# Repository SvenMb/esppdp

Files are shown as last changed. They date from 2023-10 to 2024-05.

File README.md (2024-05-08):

#What is this?

This is the source repository for esppdp, which is a tiny VT-102 scale model housing an
ESP32 emulating a PDP11. You can connect a BlueTooth keyboard to it and play the
original Tetris, or do some die-hard computing on 2.11BSD.

#Why?

Well, someone had to put back the 'mini' in 'minicomputer', right?

---

This fork contains a set of patches to correct build errors in IDF 5.0
Ian Schofield (Isysxp)
October 2023

---

This fork integrates the sunton ESP32 2832S028 board. I try to do this in a way it simplifys the integration of other boards.
Patched for IDF 5.2.1

SvenMb
April 2024

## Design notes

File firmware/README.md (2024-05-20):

This is the code for a PDP11 simulation on an ESP32. It also contains some code for turning
an attached LCD into a VT52/IE15 terminal as well as using a BlueTooth keyboard as an input device.

Flash it onto a board, turn it on. If you want to use a keyboard, make sure it's discoverable
over BlueTooth within the first few seconds of the ESP32 turning on. Note that the paired
BT device afterwards will be detected automatically. Unfortunately there's no easy way to clear
the pairing to use a different keyboard without erasing the flash of the ESP32 (idf.py erase-flash).

This firmware works on either the final hardware (as detailed in the ../pcb directory) as well
as a standard ESP32-Wrover-Kit development board + LCD and a modified Sunton 2432S028 board. You can configure which board to run on
in menuconfig. (If your LCDs backlight doesn't turn on, you selected the wrong one.)

The firmware embeds a floppy disk containing RTX-11 as well as Tetris, and will start this up
automatically unless a FAT-formatted micro-SD-card with a file called 'rq.dsk' is detected. If
this file is detected, the firmware will configure a larger PDP11 and will start from the disk.
A pre-configured 2.11BSD disk has been provided in ../hard-disk-image.

To quicken uploads (if you're developing the code), you can comment out the
spiffs_create_partition_image line in CMakeLists.txt. This'll stop 'idf.py flash'
from uploading the Tetris floppy every time.

This firmware is developed on the current (11 jan 2021) master branch of ESP-IDF, but will likely
compile on ESP-IDF 4.2 and possibly other versions.

As of April 2024 it is patched for latest ESP-IDF 5.2.1 and compiles with that.

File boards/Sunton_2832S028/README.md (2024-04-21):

# Sunton ESP32 2832S028

The Sunton ESP32 2832S028 is avaiable for very cheap and integrates most of the needed hardware to run this PDP11 emulator.
Unfortunately they decided not to include PSRAM, so we have to add it to the board. But it is not that complicated.

I only have the newer version of this board with a ST7789 display, so you are are bit on yourself if you want to use the
older version with ILI9341, since the board layout changed.

## Modifications

Board before modification:
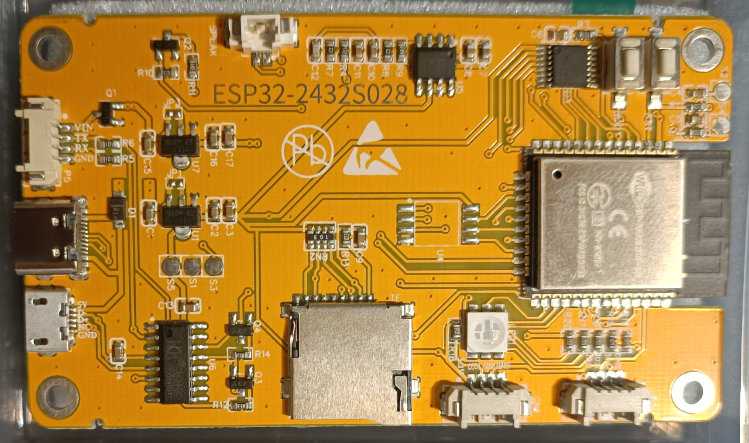
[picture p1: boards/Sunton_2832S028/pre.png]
pre modification


You have to remove the RGB-led and cut two lines:
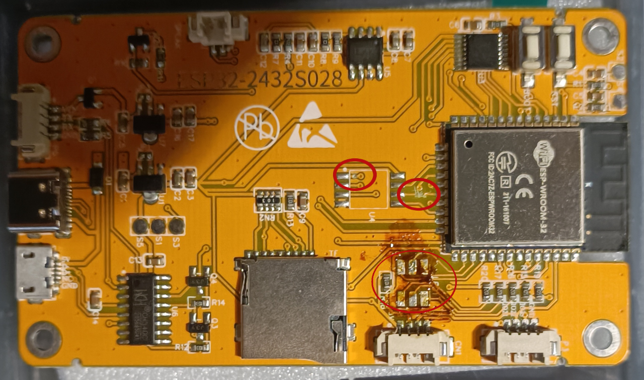
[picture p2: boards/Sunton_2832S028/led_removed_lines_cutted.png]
LED removal and lines cut


Now you can solder the PSRAM chip and add lines to the IO16, IO17 exposed on the former led place. Also add 10k pull-up as you can see here:
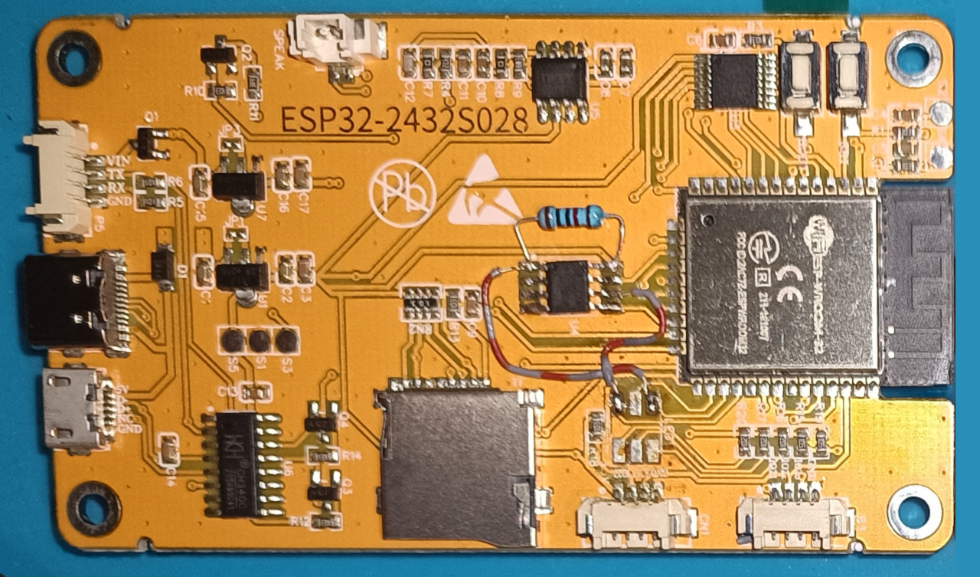
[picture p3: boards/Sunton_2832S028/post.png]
post modification


## flash firmware

after flashing the firmware and inserting the sdcard with the harddrive image, BSD 2.11 will boot:
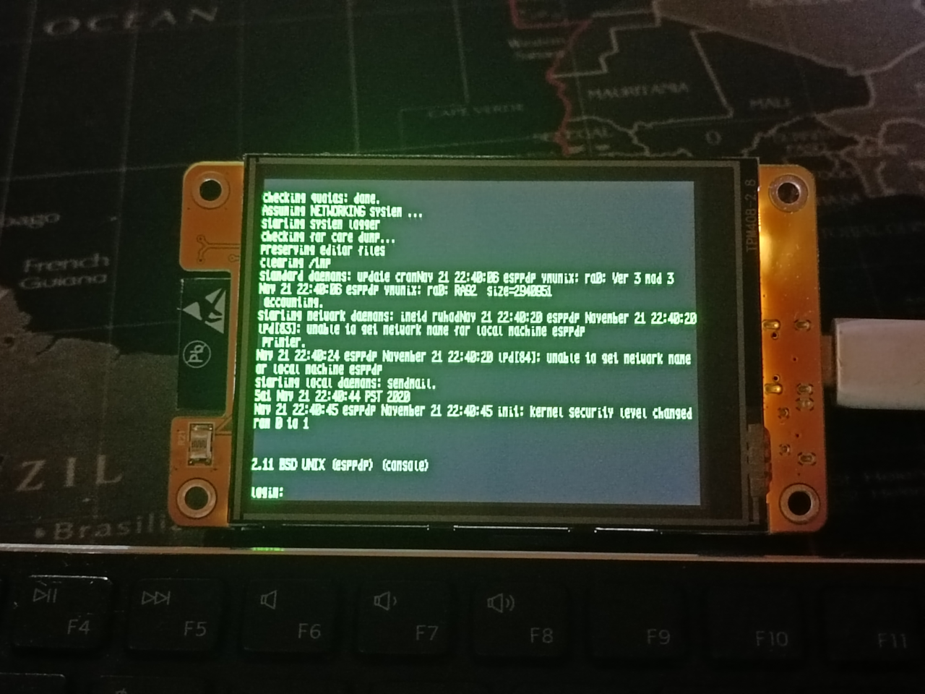
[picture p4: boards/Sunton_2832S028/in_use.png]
in use


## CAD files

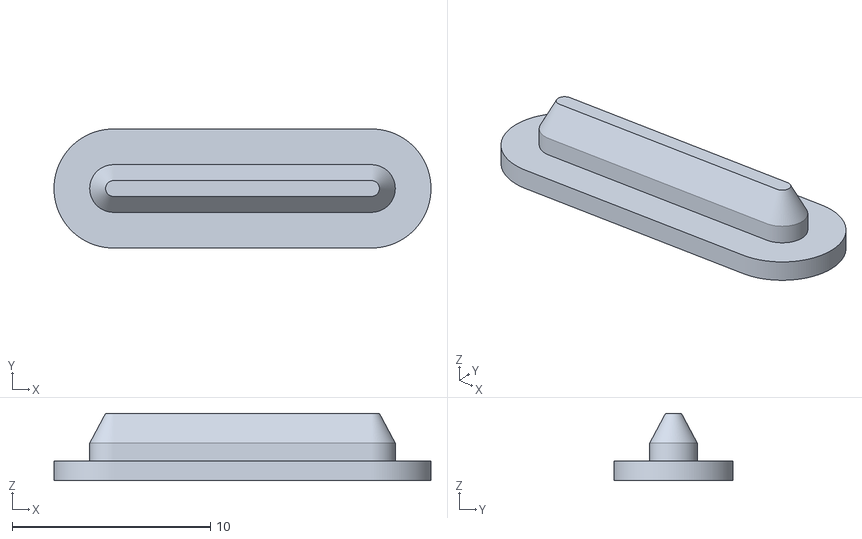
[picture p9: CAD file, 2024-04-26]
boards/Sunton_2832S028/case/MicroSD_2432S028.stl
19.0 x 6.00 x 3.40

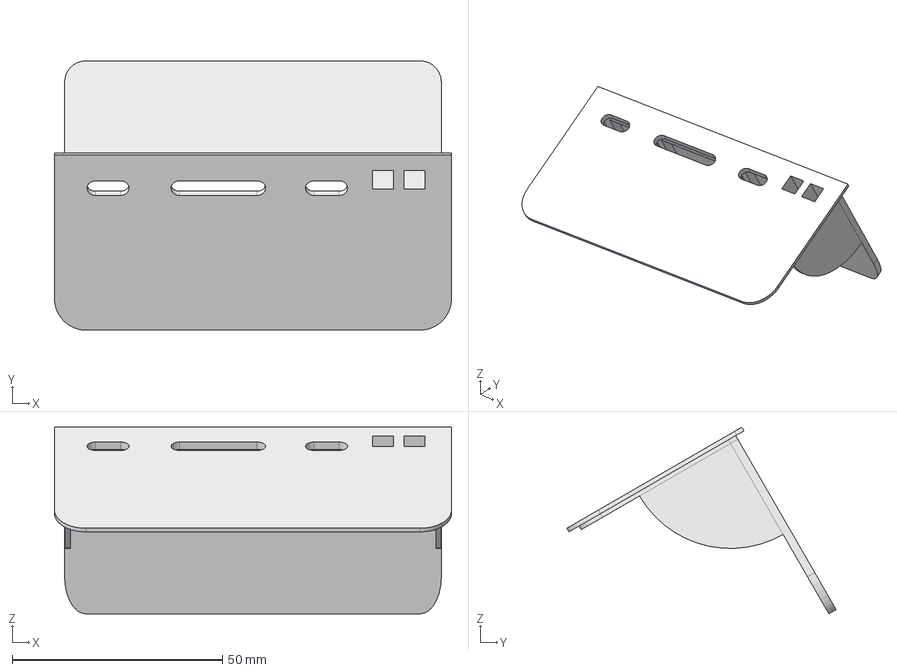
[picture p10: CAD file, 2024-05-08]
boards/Sunton_2832S028/case/2432S028_inner_03.FCStd
94.5 x 64.1 x 44.4 mm

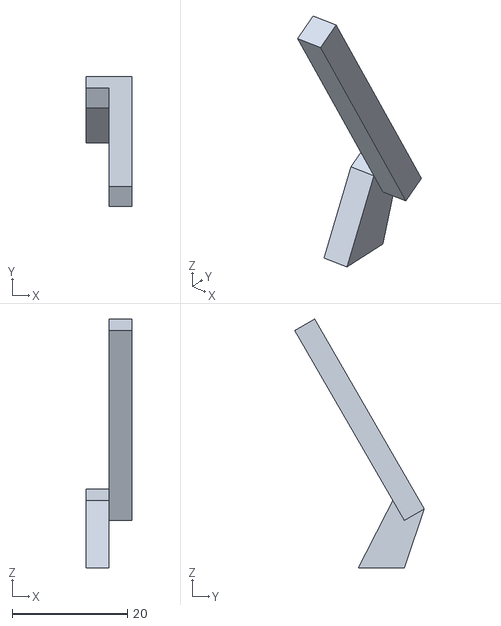
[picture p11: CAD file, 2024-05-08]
boards/Sunton_2832S028/case/2432S028_Pin_Reset.stl
8.00 x 22.5 x 43.1

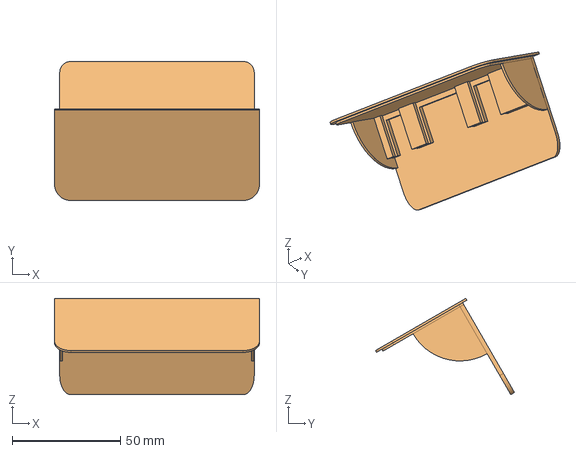
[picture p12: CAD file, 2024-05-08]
boards/Sunton_2832S028/case/2432S028_pins.FCStd
94.5 x 64.1 x 44.4 mm
Connect004

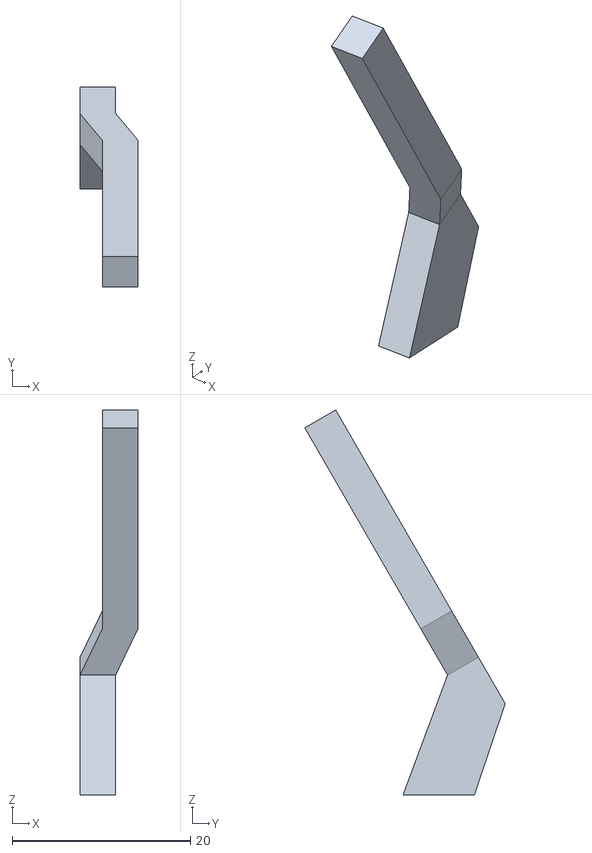
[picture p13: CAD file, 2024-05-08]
boards/Sunton_2832S028/case/2432S028_Pin_Boot.stl
6.50 x 22.5 x 43.1

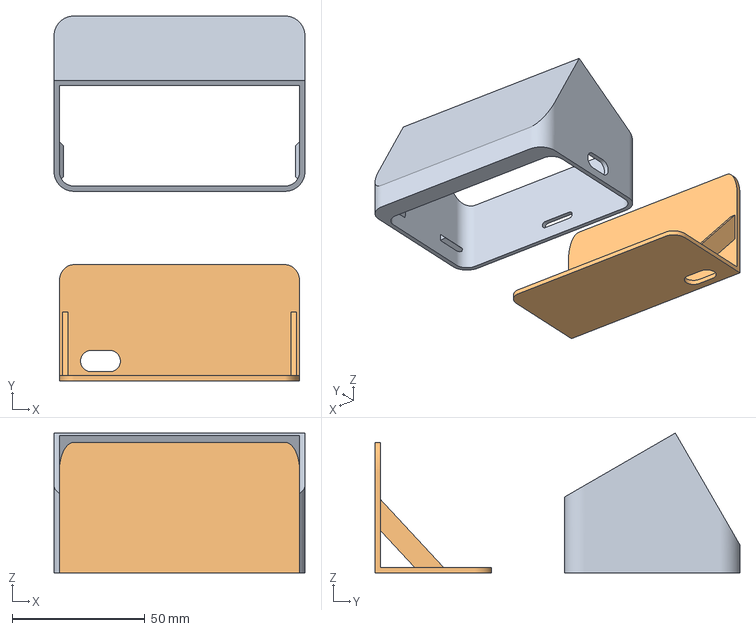
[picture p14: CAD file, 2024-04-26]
boards/Sunton_2832S028/case/2432S028_inner.FCStd
94.5 x 137.4 x 52.7 mm
Main (Meshed)
inner

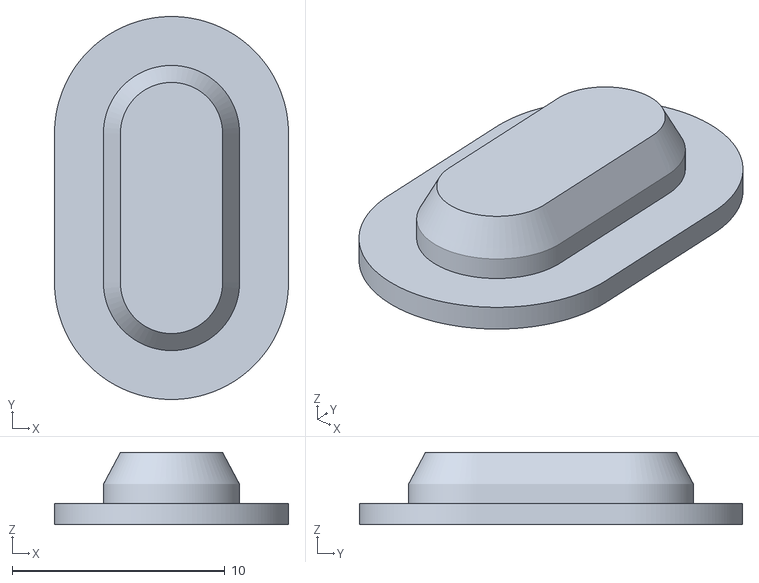
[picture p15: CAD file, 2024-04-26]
boards/Sunton_2832S028/case/2432S028_USB.stl
11.0 x 18.0 x 3.40

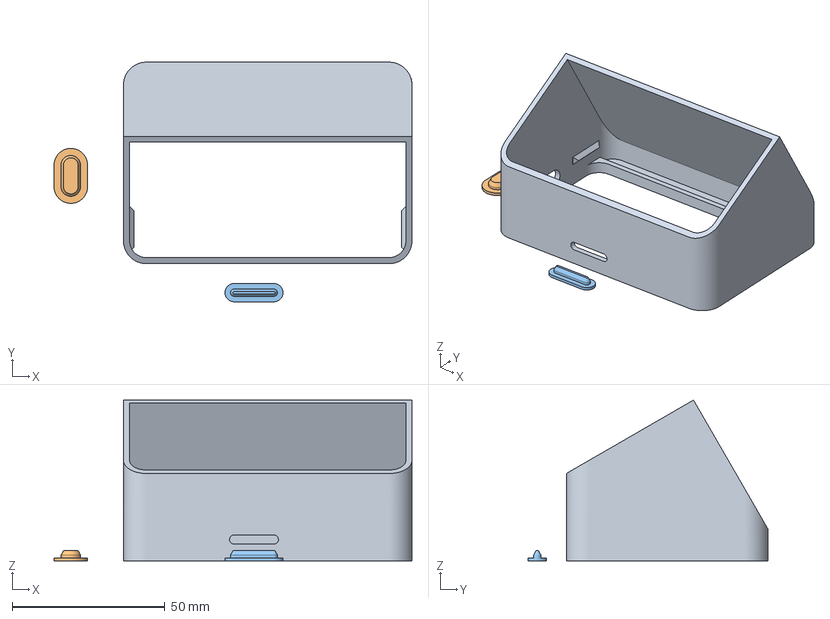
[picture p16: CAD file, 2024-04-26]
boards/Sunton_2832S028/case/2432S028.FCStd
117.2 x 78.5 x 52.7 mm
Main (Meshed)
Deckel_USB (Meshed)
Deckel MicroSD (Meshed)

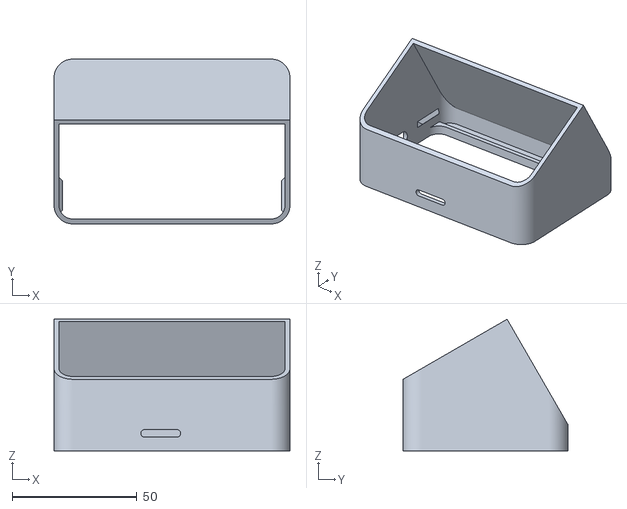
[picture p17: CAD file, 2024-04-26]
boards/Sunton_2832S028/case/2432S028_outer.stl
94.5 x 66.0 x 52.7

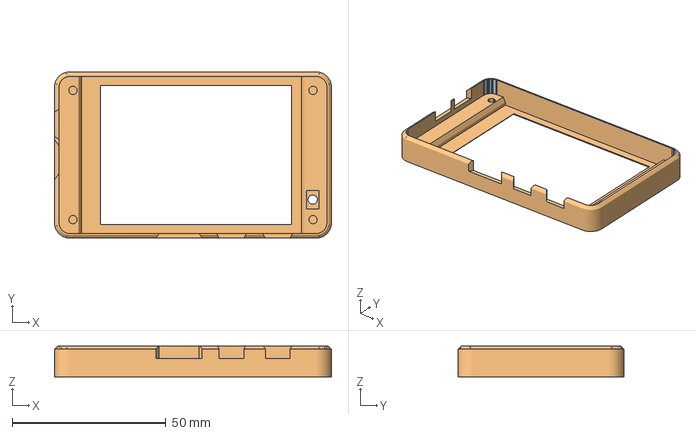
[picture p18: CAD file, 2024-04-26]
boards/Sunton_2832S028/case/2432S028_Bezel.FCStd
90.0 x 54.0 x 10.0 mm
Connect (gespiegelt)
Connect (gespiegelt) (Meshed)

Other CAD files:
boards/Spritetm_final/case/vt100.scad
boards/Sunton_2832S028/case/2432S028_Bezel.stl
boards/Sunton_2832S028/case/2432S028_inner.stl

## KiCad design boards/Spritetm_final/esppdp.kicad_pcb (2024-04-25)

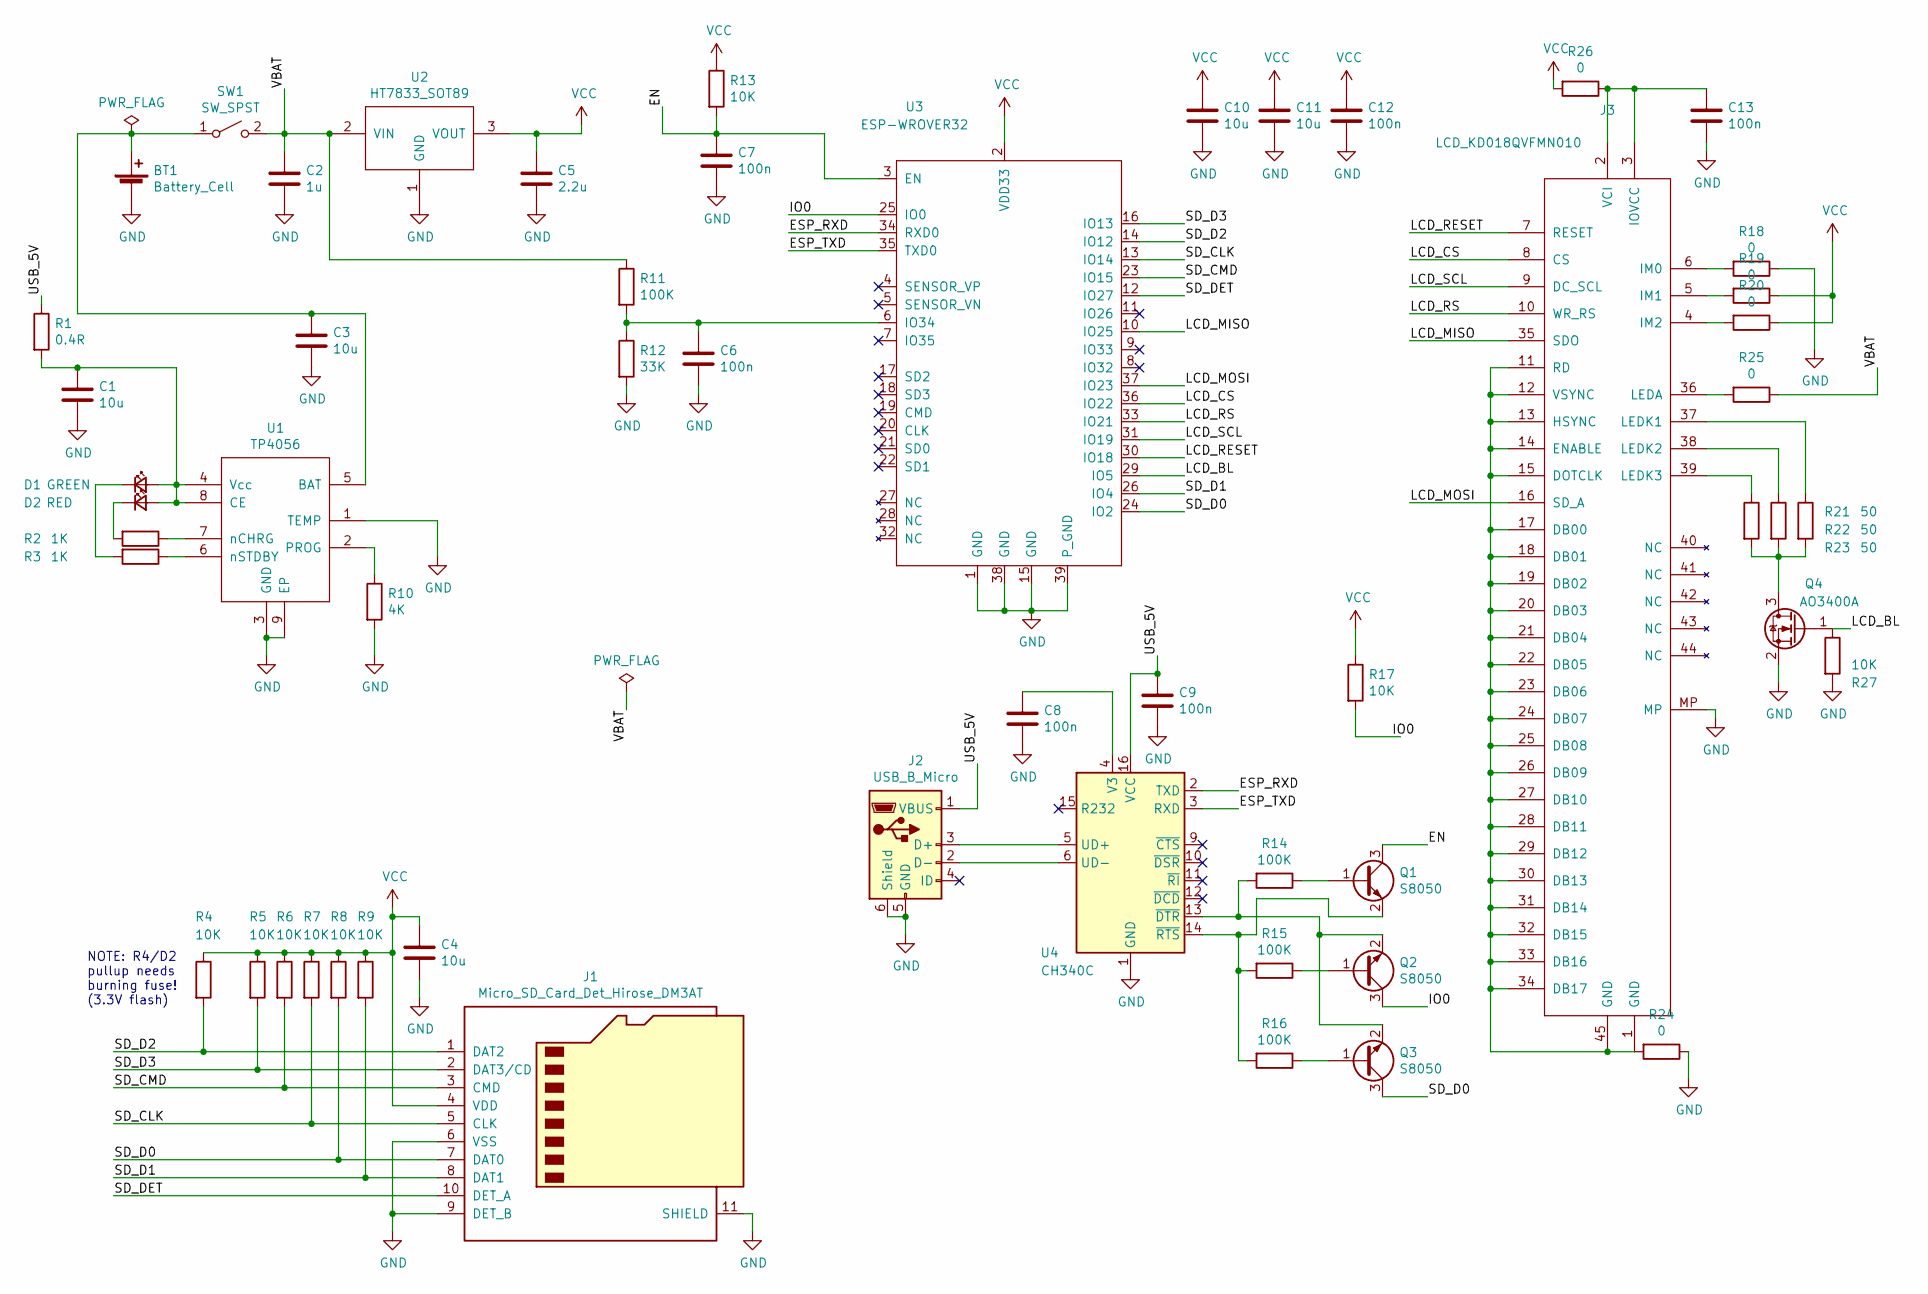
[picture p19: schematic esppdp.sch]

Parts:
BT1: Battery_Cell; PinHeader_1x02_P2.54mm_Vertical
C1, C3, C4, C10, C11: 10u; C_0805_2012Metric
C2: 1u; C_0603_1608Metric
C5: 2.2u; C_0603_1608Metric
C6, C7, C8, C9, C12, C13: 100n; C_0603_1608Metric
D1: GREEN; LED_0603_1608Metric
D2: RED; LED_0603_1608Metric
J1: Micro_SD_Card_Det_Hirose_DM3AT; microSD_HC_Hirose_DM3AT-SF-PEJM5
J2: USB_B_Micro; USB_Micro-B_China_MK5P
J3: LCD_KD018QVFMN010; Hirose_FH12-45S-0.5SH_1x45-1MP_P0.50mm_Horizontal_Descendin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
Q1, Q2, Q3: S8050; SOT-23
Q4: AO3400A; SOT-23
R1: 0.4R; R_0603_1608Metric
R2, R3: 1K; R_0603_1608Metric
R4, R5, R6, R7, R8, R9, R13, R17, R27: 10K; R_0603_1608Metric
R10: 4K; R_0603_1608Metric
R11, R14, R15, R16: 100K; R_0603_1608Metric
R12: 33K; R_0603_1608Metric
R18, R19, R20, R24, R25, R26: 0; R_0603_1608Metric
R21, R22, R23: 50; R_0603_1608Metric
SW1: SW_SPST; PinHeader_1x02_P2.54mm_Vertical
U1: TP4056; SOIC-8-1EP_3.9x4.9mm_P1.27mm_EP2.29x3mm
U2: HT7833_SOT89; SOT-89-3
U3: ESP-WROVER32; ESP-WROVER-MOD
U4: CH340C; SOIC-16_3.9x9.9mm_P1.27mm

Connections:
/EN: C7.1, Q1.3 (C), R13.2, U3.3 (EN)
/ESP_RXD: U3.34 (RXD0), U4.2 (TXD)
/ESP_TXD: U3.35 (TXD0), U4.3 (RXD)
/IO0: Q2.3 (C), R17.2, U3.25 (IO0)
/LCD_BL: Q4.1 (G), R27.1, U3.29 (IO5)
/LCD_CS: J3.8 (CS), U3.36 (IO22)
/LCD_MISO: J3.35 (SDO), U3.10 (IO25)
/LCD_MOSI: J3.16 (SD_A), U3.37 (IO23)
/LCD_RESET: J3.7 (RESET), U3.30 (IO18)
/LCD_RS: J3.10 (WR_RS), U3.33 (IO21)
/LCD_SCL: J3.9 (DC_SCL), U3.31 (IO19)
/SD_CLK: J1.5 (CLK), R7.2, U3.13 (IO14)
/SD_CMD: J1.3 (CMD), R6.2, U3.23 (IO15)
/SD_D0: J1.7 (DAT0), Q3.3 (C), R8.2, U3.24 (IO2)
/SD_D1: J1.8 (DAT1), R9.2, U3.26 (IO4)
/SD_D2: J1.1 (DAT2), R4.2, U3.14 (IO12)
/SD_D3: J1.2 (DAT3/CD), R5.2, U3.16 (IO13)
/SD_DET: J1.10 (DET_A), U3.12 (IO27)
/USB_5V: C9.1, J2.1 (VBUS), R1.1, U4.16 (VCC)
/VBAT: C2.1, R11.1, R25.1, SW1.2 (B), U2.2 (VIN)
GND: BT1.2 (-), C1.2, C2.2, C3.2, C4.2, C5.2, C6.2, C7.2, C8.2, C9.2, C10.2, C11.2, C12.2, C13.2, J1.6 (VSS), J1.9 (DET_B), J1.11 (SHIELD), J2.5 (GND), J2.6 (Shield), J3.MP, Q4.2 (S), R10.2, R12.2, R18.1, R24.1, R27.2, U1.1 (TEMP), U1.3 (GND), U1.9 (EP), U2.1 (GND), U3.1 (GND), U3.15 (GND), U3.38 (GND), U3.39 (P_GND), U4.1 (GND)
unnamed: BT1.1 (+), C3.1, SW1.1 (A), U1.5 (BAT)
unnamed: C1.1, D1.2 (A), D2.2 (A), R1.2, U1.4 (Vcc), U1.8 (CE)
unnamed: C6.1, R11.2, R12.1, U3.6 (IO34)
unnamed: C8.1, U4.4 (V3)
unnamed: C13.1, J3.2 (VCI), J3.3 (IOVCC), R26.1
unnamed: D1.1 (K), R3.2
unnamed: D2.1 (K), R2.2
unnamed: J2.2 (D-), U4.6 (UD-)
unnamed: J2.3 (D+), U4.5 (UD+)
unnamed: J3.1 (GND), J3.11 (RD), J3.12 (VSYNC), J3.13 (HSYNC), J3.14 (ENABLE), J3.15 (DOTCLK), J3.17 (DB00), J3.18 (DB01), J3.19 (DB02), J3.20 (DB03), J3.21 (DB04), J3.22 (DB05), J3.23 (DB06), J3.24 (DB07), J3.25 (DB08), J3.26 (DB09), J3.27 (DB10), J3.28 (DB11), J3.29 (DB12), J3.30 (DB13), J3.31 (DB14), J3.32 (DB15), J3.33 (DB16), J3.34 (DB17), J3.45 (GND), R24.2
unnamed: J3.4 (IM2), R20.2
unnamed: J3.5 (IM1), R19.2
unnamed: J3.6 (IM0), R18.2
unnamed: J3.36 (LEDA), R25.2
unnamed: J3.37 (LEDK1), R23.1
unnamed: J3.38 (LEDK2), R22.1
unnamed: J3.39 (LEDK3), R21.1
unnamed: Q1.1 (B), R14.1
unnamed: Q1.2 (E), R15.2, R16.2, U4.14 (~RTS)
unnamed: Q2.1 (B), R15.1
unnamed: Q2.2 (E), Q3.2 (E), R14.2, U4.13 (~DTR)
unnamed: Q3.1 (B), R16.1
unnamed: Q4.3 (D), R21.2, R22.2, R23.2
unnamed: R2.1, U1.7 (nCHRG)
unnamed: R3.1, U1.6 (nSTDBY)
unnamed: R10.1, U1.2 (PROG)
VCC: C4.1, C5.1, C10.1, C11.1, C12.1, J1.4 (VDD), R4.1, R5.1, R6.1, R7.1, R8.1, R9.1, R13.1, R17.1, R19.1, R20.1, R26.2, U2.3 (VOUT), U3.2 (VDD33)

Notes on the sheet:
NOTE: R4/D2 pullup needs burning fuse! (3.3V flash)

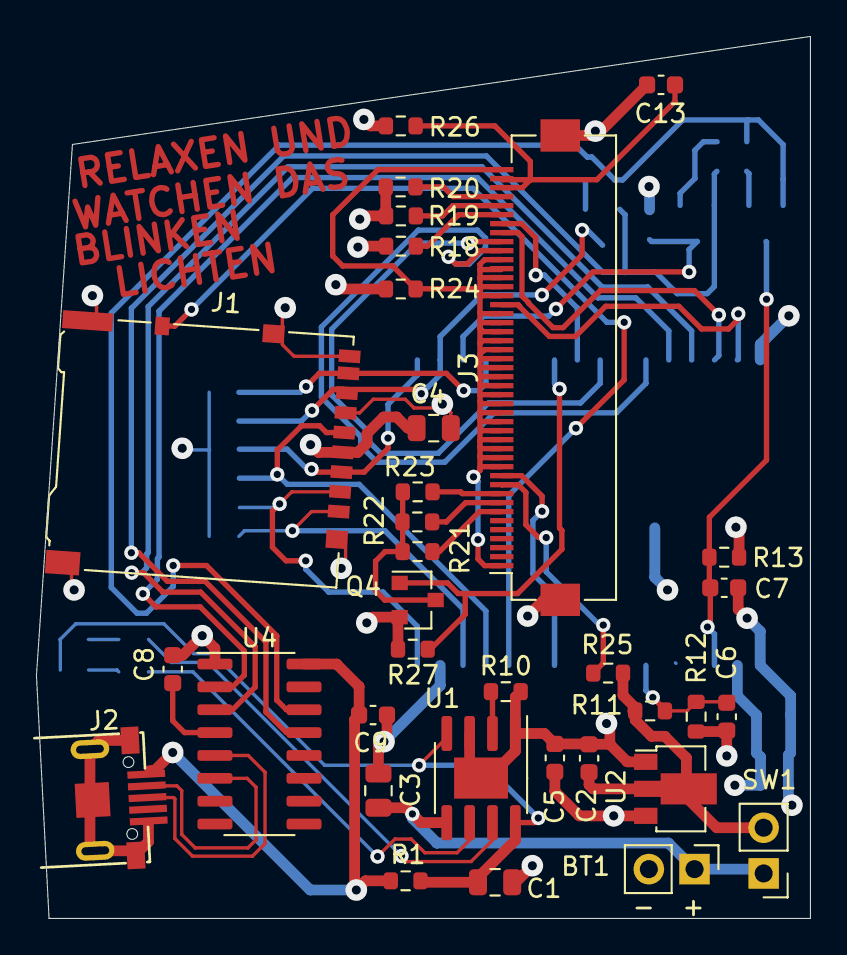
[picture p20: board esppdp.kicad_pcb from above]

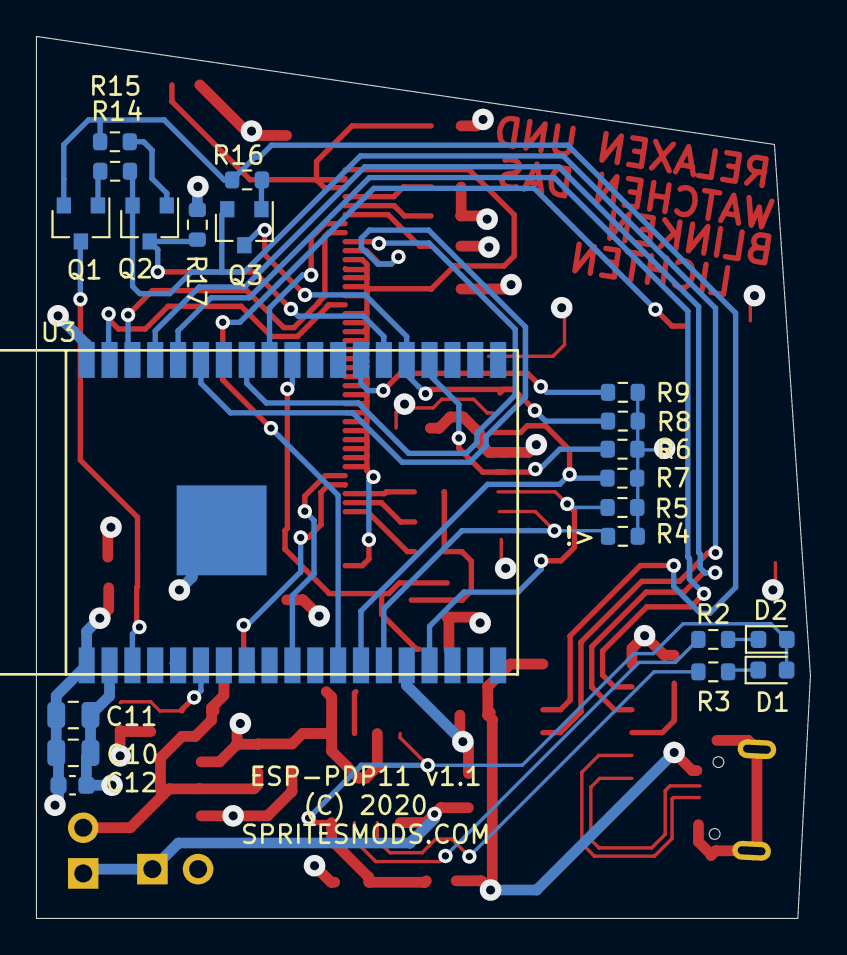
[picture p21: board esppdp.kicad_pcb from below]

Board: 4 copper layers, 43.0 x 49.0 mm, 55 parts (21 on the bottom side), 48 nets.

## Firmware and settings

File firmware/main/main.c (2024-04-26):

//Main code for pdp11 emulator thing
/*
 * ----------------------------------------------------------------------------
 * "THE BEER-WARE LICENSE" (Revision 42):
 * Jeroen Domburg <jeroen@spritesmods.com> wrote this file. As long as you retain 
 * this notice you can do whatever you want with this stuff. If we meet some day, 
 * and you think this stuff is worth it, you can buy me a beer in return. 
 * ----------------------------------------------------------------------------
 */

/*
 * ----------------------------------------------------------------------------
 * Added SPI connected SDcards and more generalized hw definition approach.
 * SvenMb
 * ----------------------------------------------------------------------------
 */


#include <stdio.h>
#include <time.h>
#include "sdkconfig.h"
#include "freertos/FreeRTOS.h"
#include "freertos/task.h"
#include "esp_system.h"

// load hardware specific definitions, use 'idf.py menuconfig' to set it 

#if CONFIG_ESPPDP_HW_WROVER_KIT
#include "hw_wrover.h"
#elif CONFIG_ESPPDP_HW_2432S028
#include "hw_2432S028.h"
#elif CONFIG_ESPPDP_HW_FINAL
#include "hw_final.h"
#else
#error ESPPDP Hardware not configured, use 'idf.py menuconfig' to choose
#endif

#include "esp_spi_flash.h"
#include "esp_err.h"
#include "esp_log.h"
#include "esp_timer.h"
#include "esp_spiffs.h"
#include "ie15lcd.h"
#include "nvs_flash.h"
#include "bthid.h"
#include "esp_vfs_fat.h"
#ifdef SD_MMC
  #include "driver/sdmmc_host.h"
#endif // SD_MMC
#ifdef SD_SPI
#include "driver/sdspi_host.h"
#endif // SD_SPI
#include "driver/spi_common.h"
#include "sdmmc_cmd.h"
#include "sdkconfig.h"
#include "wifi_if.h"
#include "wifid.h"
#include "wifid_iface.h"
#include "esp_timer.h"

#define TAG "main"

int main(int argc, char **argv);

#if CONFIG_HEAP_TRACING_STANDALONE
#include "esp_heap_trace.h"
#define NUM_RECORDS 100
static heap_trace_record_t trace_record[NUM_RECORDS]; // This buffer must be in internal RAM
#endif

//ESP-IDF doesn't implement nanosleep, but SIMH needs it. We implement it here
//using an esp_timer. (Note this code is not re-entrant, do not try to sleep
//from multiple threads, if you need a generic nanosleep implementation look
//elsewhere!)

static esp_timer_handle_t nanosleep_timer;
static TaskHandle_t nanosleep_task = NULL;

void nanosleep_callback(void *arg) {
	xTaskNotifyGive(nanosleep_task);
}

void nanosleep_init() {
	const esp_timer_create_args_t args={
		.callback=nanosleep_callback,
		.arg=NULL,
		.dispatch_method=ESP_TIMER_TASK
	};
	esp_timer_create(&args, &nanosleep_timer);
}

//note: not reentrant!
int nanosleep(const struct timespec *req, struct timespec *rem) {
	//Note: We don't have signals; no need to write to rem
	nanosleep_task=xTaskGetCurrentTaskHandle();
	uint64_t wait_us=req->tv_nsec/1000UL+req->tv_sec*1000000UL;
	esp_timer_start_once(nanosleep_timer, wait_us);
	ulTaskNotifyTake(pdFALSE, portMAX_DELAY);
	return 0;
}



void app_main(void) {
	esp_err_t ret;
#if CONFIG_HEAP_TRACING_STANDALONE
	ESP_ERROR_CHECK( heap_trace_init_standalone(trace_record, NUM_RECORDS) );
#endif

	//Initialize NVS
	ret = nvs_flash_init();
	if (ret == ESP_ERR_NVS_NO_FREE_PAGES || ret == ESP_ERR_NVS_NEW_VERSION_FOUND) {
		ESP_ERROR_CHECK(nvs_flash_erase());
		ret = nvs_flash_init();
	}
	ESP_ERROR_CHECK(ret);

	ie15_init();
	//We cheat here: as the buffer in the IE15 emu is only 8 bytes, the following routine
	//will only finish after the initialization is complete.
	const char signon[]="Initializing emulator...\r\n";
	for (const char *p=signon; *p!=0; p++) ie15_sendchar(*p);

#if !defined(SD_NONE)
	//Initialize SD-card, if possible
	ESP_LOGI(TAG,"Initialize SD-card");
	esp_vfs_fat_sdmmc_mount_config_t mount_config = {
		.format_if_mount_failed = false,
		.max_files = 2,
		.allocation_unit_size = 16 * 1024
	};
	sdmmc_card_t* card;
  #if defined(SD_MMC)
	ESP_LOGI(TAG,"Create SDMMC_HOST");
	sdmmc_host_t host = SDMMC_HOST_DEFAULT();
//	host.max_freq_khz=5000;
	sdmmc_slot_config_t slot_config = SDMMC_SLOT_CONFIG_DEFAULT();
	// GPIOs 15, 2, 4, 12, 13 should have external 10k pull-ups.
	// Internal pull-ups are not sufficient. However, enabling internal pull-ups
	// does make a difference some boards, so we do that here.
	gpio_set_pull_mode(SD_MMC_CMD, GPIO_PULLUP_ONLY);	// CMD, needed in 4- and 1- line modes
	gpio_set_pull_mode(SD_MMC_D0, GPIO_PULLUP_ONLY);	// D0, needed in 4- and 1-line modes
	gpio_set_pull_mode(SD_MMC_D1, GPIO_PULLUP_ONLY);	// D1, needed in 4-line mode only
	gpio_set_pull_mode(SD_MMC_D2, GPIO_PULLUP_ONLY);	// D2, needed in 4-line mode only
	gpio_set_pull_mode(SD_MMC_D3, GPIO_PULLUP_ONLY);	// D3, needed in 4- and 1-line modes
	ESP_LOGI(TAG,"Initialize VFS via SDMMC\n");
	ret = esp_vfs_fat_sdmmc_mount("/sdcard", &host, &slot_config, &mount_config, &card);
  #elif defined(SD_SPI)
	ESP_LOGI(TAG,"Create SDSPI_HOST\n");
	sdmmc_host_t host = SDSPI_HOST_DEFAULT();
	host.slot = SD_SPI_HOST;
	spi_bus_config_t bus_cfg = {
        	.mosi_io_num = SD_SPI_MOSI,
        	.miso_io_num = SD_SPI_MISO,
        	.sclk_io_num = SD_SPI_SCLK,
        	.quadwp_io_num = -1,
        	.quadhd_io_num = -1,
        	.max_transfer_sz = 4000,
	};
	ESP_LOGI(TAG,"Initialize SPI_BUS\n");
	// ret = spi_bus_initialize(host.slot, &bus_cfg, SDSPI_DEFAULT_DMA);
	ret = spi_bus_initialize(host.slot, &bus_cfg, SD_SPI_DMA);
	if (ret != ESP_OK) {
		ESP_LOGE(TAG,"Failed to initialize bus.");
		return;
	}    
	sdspi_device_config_t slot_config = SDSPI_DEVICE_CONFIG_DEFAULT();
	slot_config.gpio_cs = SD_SPI_CS;
	slot_config.host_id = host.slot;

	ESP_LOGI(TAG,"Initialize VFS via SDSPI\n");
	//ret = esp_vfs_fat_sdmmc_mount("/sdcard", &host, &slot_config, &mount_config, &card);
	ret = esp_vfs_fat_sdspi_mount("/sdcard", &host, &slot_config, &mount_config, &card);
  #else
    #error SD_MMC or SD_SPI or SD_NONE must be defined
#endif // defined(SD_MMC) // defined(SD_SPI)
	if (ret != ESP_OK) {
		ESP_LOGE(TAG, "SD-card: Failed to mount filesystem.");
		const char noflopstr[]="No SD card. Trying boot from built-in floppy.\r\n";
		for (const char *p=noflopstr; *p!=0; p++) ie15_sendchar(*p);
	} else {
		sdmmc_card_print_info(stdout, card);
	}
#else
	ESP_LOGI(TAG,"No SD-Card defined");
#endif // defined(SD_NONE)

#if !defined(SPIFFS_NONE)
	//Mount spiffs. This contains (a) floppy image(s).
	esp_vfs_spiffs_conf_t conf = {
		.base_path = "/spiffs",
		.partition_label = NULL,
		.max_files = 2,
		.format_if_mount_failed = true
	};
	// Use settings defined above to initialize and mount SPIFFS filesystem.
	// Note: esp_vfs_spiffs_register is an all-in-one convenience function.
	ret = esp_vfs_spiffs_register(&conf);

	if (ret != ESP_OK) {
		if (ret == ESP_FAIL) {
			ESP_LOGE(TAG, "Failed to mount filesystem");
		} else if (ret == ESP_ERR_NOT_FOUND) {
			ESP_LOGE(TAG, "Failed to find SPIFFS partition");
		} else {
			ESP_LOGE(TAG, "Failed to initialize SPIFFS (%s)", esp_err_to_name(ret));
		}
		return;
	}
#else
	ESP_LOGI(TAG,"No SPIFFS defined");
#endif // defined(SPIFFS_NONE)
	
	bthid_start();

	nanosleep_init();

#if CONFIG_HEAP_TRACING_STANDALONE
	ESP_ERROR_CHECK( heap_trace_init_standalone(trace_record, NUM_RECORDS) );
	ESP_ERROR_CHECK( heap_trace_start(HEAP_TRACE_LEAKS) );
#endif
	
	//Start up main SIMH emulator
	char *args[]={"simh", 0};
	main(1, args);		//Note: This is in scp.c and is the SIMH main routine.
	fflush(stdout);
	esp_restart();
}

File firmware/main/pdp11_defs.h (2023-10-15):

/* pdp11_defs.h: PDP-11 simulator definitions

   Copyright (c) 1993-2017, Robert M Supnik

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
   Except as contained in this notice, the name of Robert M Supnik shall not be
   used in advertising or otherwise to promote the sale, use or other dealings
   in this Software without prior written authorization from Robert M Supnik.

   The author gratefully acknowledges the help of Max Burnet, Megan Gentry,
   and John Wilson in resolving questions about the PDP-11

   10-Feb-17    RMS     Fixed RJS11 register block length (Mark Hill)
   19-Jan-17    RMS     Moved CR11 to BR6, leaving CD11 at BR4 (Mark Pizzolato)
   10-Mar-16    RMS     Added UC15 support
   30-Dec-15    RMS     Added NOBVT option
   23-Oct-13    RMS     Added cpu_set_boot prototype
   02-Sep-13    RMS     Added third Massbus adapter and RS drive
   11-Dec-11    RMS     Fixed priority of PIRQ vs IO; added INT_INTERNALn
   22-May-10    RMS     Added check for 64b definitions
   19-Nov-08    RMS     Moved I/O support routines to I/O library
   16-May-08    RMS     Added KE11A, DC11 support
   02-Feb-08    RMS     Fixed DMA memory address limit test (found by John Dundas)
   25-Jan-08    RMS     Added RC11, KG11A support (from John Dundas)
   16-Dec-06    RMS     Added TA11 support
   29-Oct-06    RMS     Added clock coscheduling
   06-Jul-06    RMS     Added multiple KL11/DL11 support
   26-Jun-06    RMS     Added RF11 support
   24-May-06    RMS     Added 11/44 DR support (from CIS diagnostic)
   17-May-06    RMS     Added CR11/CD11 support (from John Dundas)
   30-Sep-04    RMS     Added Massbus support
                        Removed Map_Addr prototype
                        Removed map argument from Unibus routines
                        Added framework for model selection
   28-May-04    RMS     Added DHQ support
   25-Jan-04    RMS     Removed local debug logging support
   22-Dec-03    RMS     Added second DEUNA/DELUA support
   18-Oct-03    RMS     Added DECtape off reel message
   19-May-03    RMS     Revised for new conditional compilation
   05-Apr-03    RMS     Fixed bug in MMR1 update (found by Tim Stark)
   28-Feb-03    RMS     Added TM logging support
   19-Jan-03    RMS     Changed mode definitions for Apple Dev Kit conflict
   11-Nov-02    RMS     Changed log definitions to be VAX compatible
   10-Oct-02    RMS     Added vector information to DIB
                        Changed DZ11 vector to Unibus standard
                        Added DEQNA/DELQA, DEUNA/DELUA support
                        Added multiple RQDX3, autoconfigure support
   12-Sep-02    RMS     Added TMSCP, KW11P,and RX211 support
   28-Apr-02    RMS     Clarified PDF ACF mnemonics
   22-Apr-02    RMS     Added HTRAP, BPOK maint register flags, MT_MAXFR
   06-Mar-02    RMS     Changed system type to KDJ11A
   20-Jan-02    RMS     Added multiboard DZ11 support
   09-Nov-01    RMS     Added bus map support
   07-Nov-01    RMS     Added RQDX3 support
   26-Oct-01    RMS     Added symbolic definitions for IO page
   19-Oct-01    RMS     Added DZ definitions
   15-Oct-01    RMS     Added logging capabilities
   07-Sep-01    RMS     Revised for multilevel interrupts
   01-Jun-01    RMS     Added DZ11 support
   23-Apr-01    RMS     Added RK611 support
   05-Apr-01    RMS     Added TS11/TSV05 support
   10-Feb-01    RMS     Added DECtape support
*/
#pragma GCC diagnostic ignored  "-Wformat"
#ifndef PDP11_DEFS_H
#define PDP11_DEFS_H   0

#ifndef VM_PDP11
#define VM_PDP11        0
#endif

#include "sim_defs.h"                                   /* simulator defns */
#include <setjmp.h>

#if defined(USE_INT64) || defined(USE_ADDR64)
#error "PDP-11 does not support 64b values!"
#endif

/* Architectural constants */

#define STKL_R          0340                            /* stack limit */
#define STKL_Y          0400
#define VASIZE          0200000                         /* 2**16 */
#define VAMASK          (VASIZE - 1)                    /* 2**16 - 1 */
#define MEMSIZE64K      0200000                         /* 2**16 */
#define UNIMEMSIZE      001000000                       /* 2**18 */
#define UNIMASK         (UNIMEMSIZE - 1)                /* 2**18 - 1 */
#define IOPAGEBASE      017760000                       /* 2**22 - 2**13 */
#define IOPAGESIZE      000020000                       /* 2**13 */
#define IOPAGEMASK      (IOPAGESIZE - 1)                /* 2**13 - 1 */
#define MAXMEMSIZE      020000000                       /* 2**22 */
#define PAMASK          (MAXMEMSIZE - 1)                /* 2**22 - 1 */
#define MEMSIZE         (cpu_unit.capac)
#define DMASK           0177777
#define BMASK           0377

/* CPU models */
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

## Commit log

2023-10-15 Update for IDF 5.0
    Correct build errors in IDF 5.0
    [ie15lcd.c, pdp11_defs.h, sim_defs.h]
2024-04-21 added pictures for sunton 2832S070 board, how to add PSRAM
2024-04-24 - making hardware more general - adding sunton 2432S028 board
2024-04-25 cleaning up
    [esppdp.kicad_pcb, esppdp.sch, vt100.scad]
2024-04-26 small changes for current idf 5.2.1 compatibility
2024-04-26 case for the 2432S028 (not a vt100 clone)
    [2432S028.FCStd, 2432S028_outer.stl, Bezel_2432S028.stl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]
2024-04-26 added lid for MicroSd slot and USB slot
    [2432S028.FCStd, MicroSD_2432S028.stl, USB_2432S028.stl]
2024-04-26 add simple inner housing
    [2432S028_inner.FCStd, 2432S028_inner.stl]
2024-05-08 added case parts
    [2432S028_Bezel.FCStd, 2432S028_Bezel.stl, 2432S028_Pin_Boot.stl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]
2024-05-20 added driver component, since it is now needed to declare it
2024-05-20 added info about current esp-idf and new sunton board to README.md

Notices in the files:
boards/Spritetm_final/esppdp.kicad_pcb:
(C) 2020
